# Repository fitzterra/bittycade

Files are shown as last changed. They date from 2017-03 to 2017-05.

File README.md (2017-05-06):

Bitty Arcade - Extremely Retro, Minimalist, Handheld Arcade Game.
=================================================================

This is my remix of an Arduino based handheld arcade game using an 8x8 LED
matrix as display.

The original inspiration and idea comes from [3CarrotsOnAStick] and is heavily
based on his [AbHhGd] - Arduino Based Hand-held Gaming Device instructable. Most
of the code and game ideas come from here, but I have had to make some heavy
code changes to compile in my environment as well as some changes that I wanted
to the code.

This device also uses the potentiometer as controler, while other devices like
this often uses 4 directional buttons. I decided to stick with the pot for now,
but this may change later.

For now the project is not completed yet, but I have a custom case designed and
it is printing now as I type, and I'm working on the code to allow rotation of
the display in 90° increments. I need this since for my case I had to rotate the
display by 90°, and I also want to clean up the display handling in the original
code which needs the sprites and coordinates to be mirrored.

I'll update here as the project progresses.

Updates
-------

* 2017-05-06: Added option for using a [rotary encoder](#rotEnc) for directional
    control.

Rotary Encoder for directional control
--------------------------------------
The initial implementation uses the optimised [Encoder] library by Paul
Stoffregen. The encoder used is a Chinese [knockoff] of the Keyes [KY-040]
rotary encoder.

In order to get this encoder to work, I had to solder a capacitor (100nF) across
each encoder output to ground. This was done right on the encoder on the board.
Without the caps, there would be too much switch bounce with totally erratic
output.

All games current has a delay during the play loop. Due to this delay the
encoder can not be polled for reliable positioning. To get around this for now,
the encoder should be connected to pins that allow external interrupts. For a
Nano or Uno, this will be pins 2 and 3, for example.
The [Encoder] library will automatically use interrupts in this case. It could
be an option to remove the delay in the main games play loop in future in order
to poll the encoder more frequently if using pins that do not support external
interrupts.

When using an encoder, the button on the encoder will also be made available via
the controller, but the individual game has to support this explicitly. An new
`Controller::anyButtonPressed` method has been added which will return true if
any button has been pressed, including an encoder button if available.

[3CarrotsOnAStick]: http://www.instructables.com/member/3CarrotsOnAStick/
[AbHhGd]: http://www.instructables.com/id/AbHhGD-the-Arduino-Based-Hand-held-Gaming-Device/
[Encoder]: http://www.pjrc.com/teensy/td_libs_Encoder.html
[knockoff]:https://www.banggood.com/KY-040-Rotary-Decoder-Encoder-Module-For-Arduino-AVR-PIC-p-914010.html 
[KY-040]: http://henrysbench.capnfatz.com/henrys-bench/arduino-sensors-and-input/keyes-ky-040-arduino-rotary-encoder-user-manual/

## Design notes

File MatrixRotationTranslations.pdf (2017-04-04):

8X8 LED Matrix Rotation Function Translations

C0 C1 C2 C3 C4 C5 C6 C7 | C0 C1 C2 C3 C4 C5 C6 C7
R0 | | | | R0
R1 | 0° | | | R1 | 90°
R2 | | | | R2
R3 | setPixel(r, c) | -> | setPixel(r, c) | R3 | setPixel(r, c) | -> | setPixel(c, rRev)
R4 | setRow(r, b) | -> | setRow(r, b) | R4 | setRow(r, b) | -> | setCol(rRev, b)
R5 | setCol(c, b) | -> | setCol(c, b) | R5 | setCol(c, b) | -> | setRow(c, inv(b))
R6 | | | | R6
R7 | | | | R7
C0 C1 C2 C3 C4 C5 C6 C7 | C0 C1 C2 C3 C4 C5 C6 C7
R0 | | | | R0
R1 | 270° | | | R1 | 180°
R2 | | | | R2
R3 | setPixel(r, c) | -> | setPixel(cRev, r) | R3 | setPixel(r, c) | -> | setPixel(rRev, cRev)
R4 | setRow(r, b) | -> | setCol(r, inv(b)) | R4 | setRow(r, b) | -> | setRow(rRev, inv(b))
R5 | setCol(c, b) | -> | setRow(cRev, b) | R5 | setCol(c, b) | -> | setCol(cRev, inv(b))
R6 | | | | R6
R7 | | | | R7

r: row number (0 – maxRows)
c: column number (0 – maxCols)
b: bit representation of row or column LEDs to switch on or off in a single byte, word, etc. depending on num LEDs in the row/col rRev: reversed row number = (maxRows – r)
cRev: reversed col number = (maxCols – c)
inv(b): function to invert a bit representation such that inv(b10011100) = b00111001

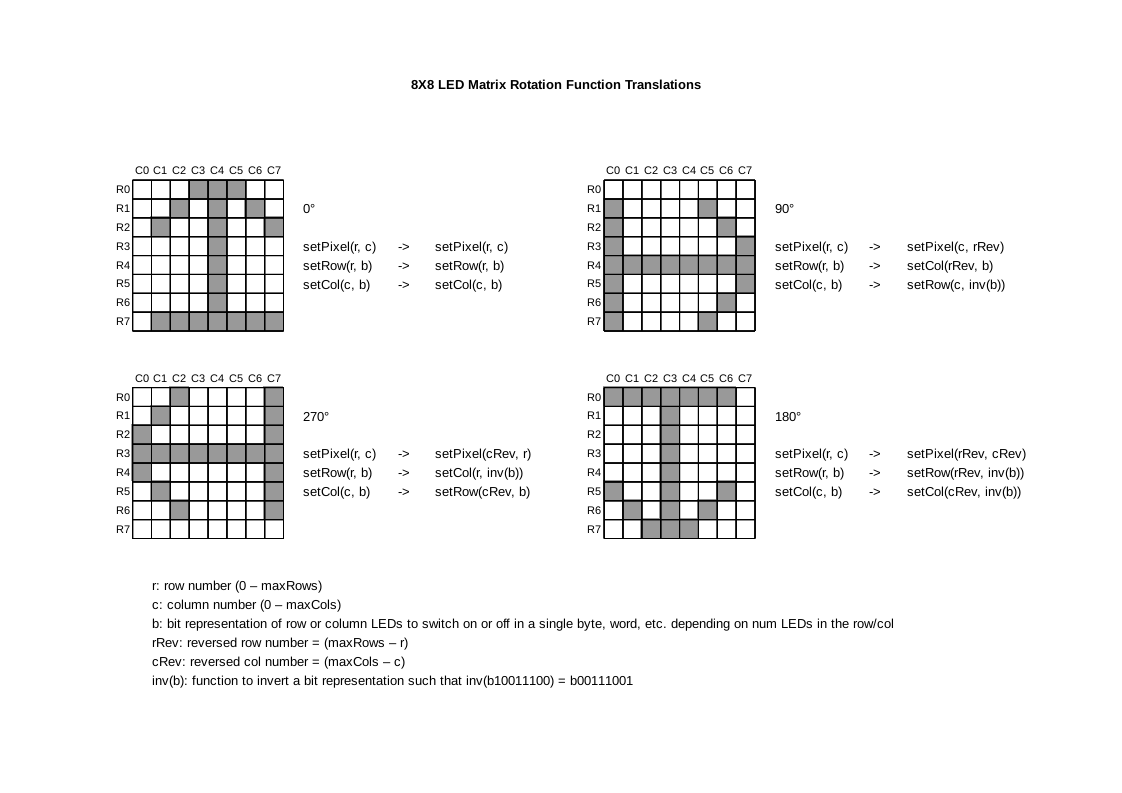
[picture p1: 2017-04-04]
MatrixRotationTranslations.png

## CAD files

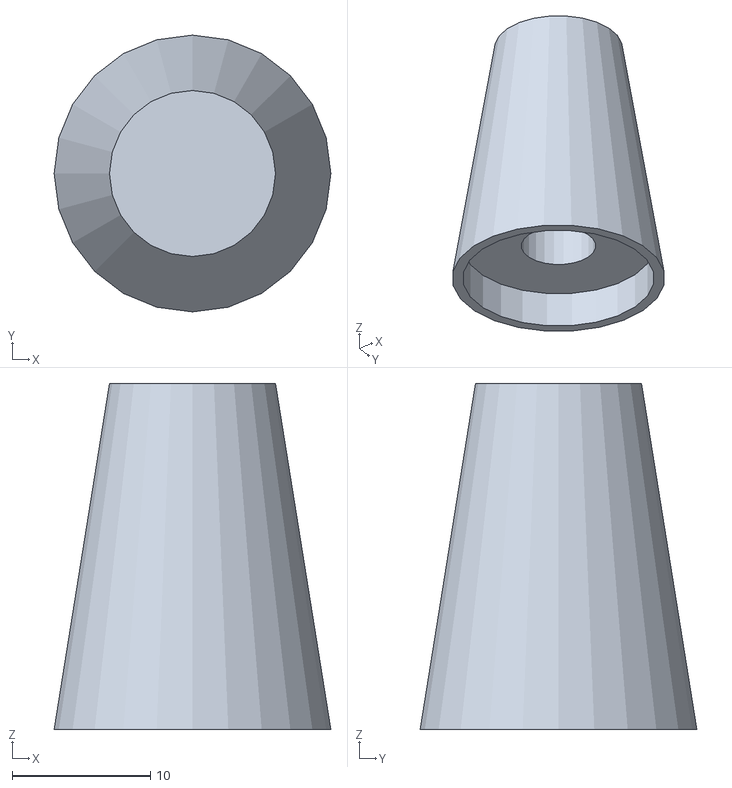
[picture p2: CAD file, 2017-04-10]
case/STLs/knob-v3.stl
20.0 x 20.0 x 25.0

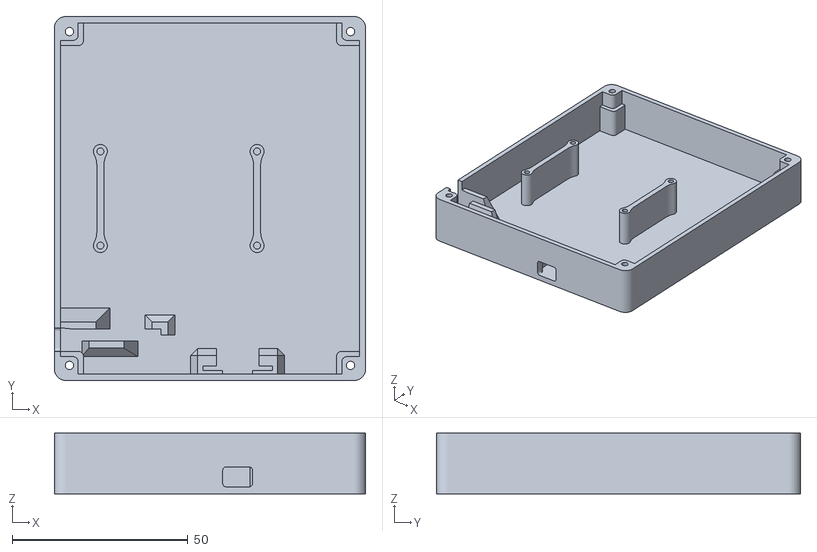
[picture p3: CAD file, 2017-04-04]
case/STLs/caseBottom-v3.stl
88.6 x 103.6 x 17.3

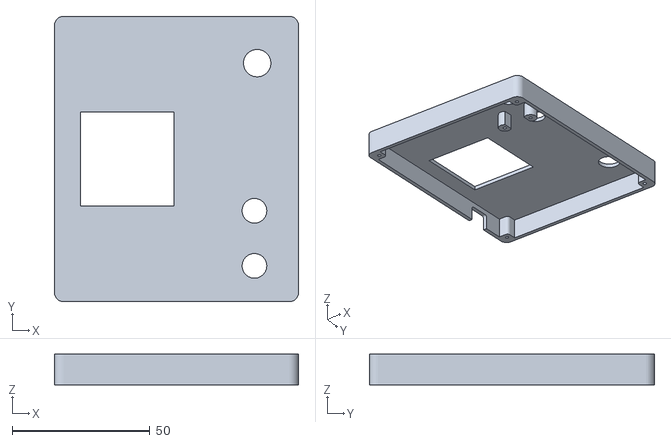
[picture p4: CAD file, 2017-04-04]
case/STLs/caseTop-v3.stl
88.6 x 103.6 x 11.2

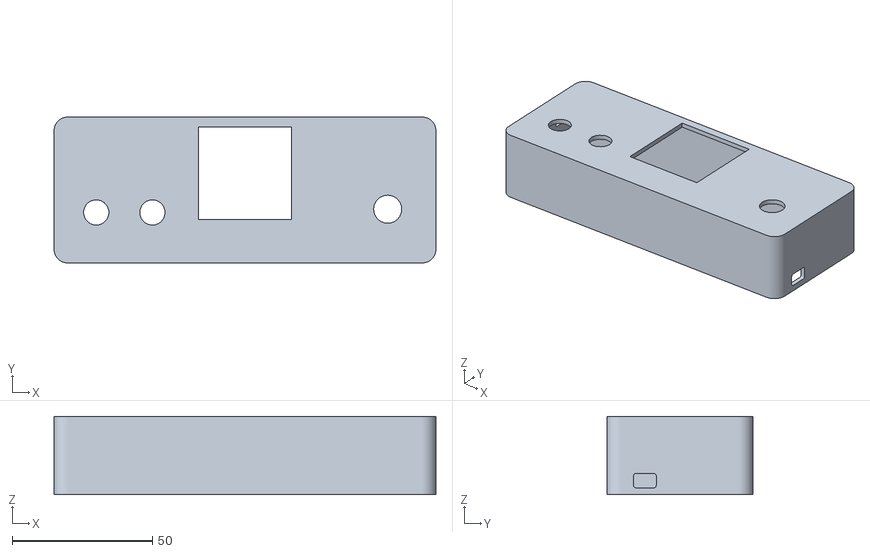
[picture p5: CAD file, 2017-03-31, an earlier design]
case/STLs/caseTop-v2.stl
136.0 x 52.0 x 27.8

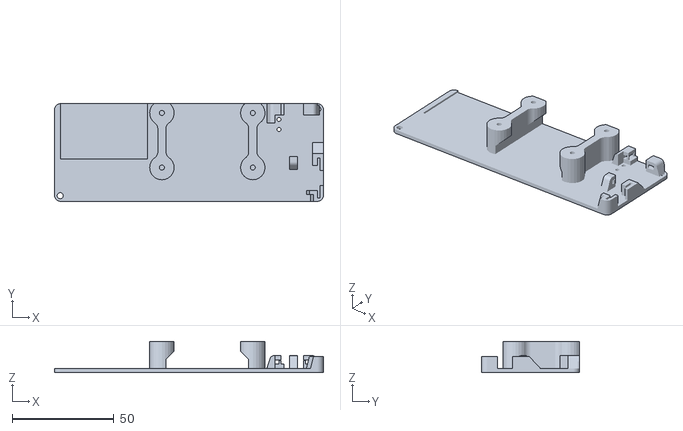
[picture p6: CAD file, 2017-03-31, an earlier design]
case/STLs/caseBottom-v2.stl
132.0 x 48.0 x 15.3

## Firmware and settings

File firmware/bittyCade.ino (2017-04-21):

#include "config.h"
#include "types.h"
#include "menu.h"
#include "pong.h"
#include "breakout.h"
#include "racing.h"
#include "snake.h"
#include "spaceInvaders.h"

Controller controller;
Display display;
Menu menu(&display, &controller);
Pong pong(&display, &controller);
BreakOut breakout(&display, &controller);
Racing racing(&display, &controller);
Snake snake(&display, &controller);
SpaceInvaders spaceinvaders(&display, &controller);

void setup() {
	Serial.begin(115200);
	randomSeed(analogRead(0));
}

void loop() {
    games game = menu.selectGame();
    Serial << "Game: " << game << endl;

    switch(game) {
        case gmPong:
            pong.play();
            break;
        case gmSpaceInvaders:
            spaceinvaders.play();
            break;
        case gmSnake:
            snake.play();
            break;
        case gmBreakOut:
            breakout.play();
            break;
        case gmRacing:
            racing.play();
            break;
    }
}

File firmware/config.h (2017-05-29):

#ifndef __CONFIG__H__
#define __CONFIG__H__

#include <stdint.h>
#include <Arduino.h>
// Make Serial streaming available to all
#include <Streaming.h>

// X Size of the LED matrix
#define LEDMATRIX_X 8
// Y Size of the LED matrix
#define LEDMATRIX_Y 8
// Set the rotation angle if needed - 0, 90, 180 or 270
#define DISPLAYROTATE 90

// Direction control. This can be a potentionmeter or a rotary encoder
#define CONTRL_POT 0
#define CONTRL_ROTARY 1
// Define which control to use here, and define the specific controller
// connections below
//#define DIRCONTR CONTRL_POT
#define DIRCONTR CONTRL_ROTARY


// Pin potentiometer is connected to
#if DIRCONTR==CONTRL_POT
    #define CONTROLLERPOTPIN A7
    // To invert the min/max directions of the poteniometer control, define
    // this:
    //#define INVERTPOTCONTROL
#else
    // Rotary encoder settings
    #define ROTARY_A 3
    #define ROTARY_B 2
    // Will use internal pullup for the button
    #define ROTARY_BUTTON 4
#endif

// Button pin - will use internal pullup
#define CONTROLLERRIGHTBUTTONPIN 5
//#define CONTROLLERRIGHTBUTTONPIN 2
// Button pin - will use internal pullup
#define CONTROLLERLEFTBUTTONPIN 6
//#define CONTROLLERLEFTBUTTONPIN 3
// Pin to which an LED can be connected which will be lit when the RIGHT button
// is pressed.
#define BUTTONLED 13
// Pins to talk to the LED display
//#define DIN 12
#define DIN 10
//#define CLK 11
#define CLK 12
//#define CS 10
#define CS 11
// This may be changed or defined elsewhere later!
#define NUM_GAMES 5 /// This excludes the Menu which is also handled as a game!
// Size of the menu sprite
#define MENUWIDTH NUM_GAMES*8
#define MENUHEIGHT 8

#endif // __CONFIG__H__

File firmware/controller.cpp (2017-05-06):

#include "controller.h"

/**
 * Controller constructor.
 * */
Controller::Controller() {
    objWidth = 0;

    pinMode(CONTROLLERRIGHTBUTTONPIN, INPUT_PULLUP);
    pinMode(CONTROLLERLEFTBUTTONPIN, INPUT_PULLUP);
    pinMode(BUTTONLED, OUTPUT);
#if DIRCONTR==CONTRL_ROTARY
    pinMode(ROTARY_BUTTON, INPUT_PULLUP);
#endif

    update();
}

void Controller::updateButtons() {
    // We are using the internal pullups for the buttons, so the state is invereted.
    rightButtonPressed = !digitalRead(CONTROLLERRIGHTBUTTONPIN);
    leftButtonPressed = !digitalRead(CONTROLLERLEFTBUTTONPIN);
    rotaryButtonPressed = !digitalRead(ROTARY_BUTTON);
}

void Controller::pause() {
    // We only enter this state when pausing is allowed and both buttons have
    // been pressed. Wait until both buttons have been released
    do {
        delay(100);
        updateButtons();
    } while(rightButtonPressed && leftButtonPressed);

    // Now we pause until any button is pressed to unpause
    do {
        delay(100);
        updateButtons();
    } while(!(rightButtonPressed || leftButtonPressed));

    // Unpaused, but wait for both buttons to be released again
    do {
        delay(100);
        updateButtons();
    } while(rightButtonPressed && leftButtonPressed);
}

#if DIRCONTR==CONTRL_POT
void Controller::updatePot() {
    // Get the pot analog position
    uint16_t potV = analogRead(CONTROLLERPOTPIN);
    // Set the real X position by mapping the pot value to the correct min and
    // max values after taking objWidth into account.
#ifdef INVERTPOTCONTROL
    xPos = map(potV, 0, 1023, xMax-objWidth, xMin);
#else
    xPos = map(potV, 0, 1023, xMin, xMax-objWidth);
#endif
}
#else
void Controller::updateEncoder() {
    xPos = encoder.read() / 4;

    if (xPos > xMax-objWidth) {
        xPos = xMax-objWidth;
        encoder.write(xPos * 4);
    } else if (xPos < xMin) {
        xPos = xMin;
        encoder.write(xPos * 4);
    }
}
#endif

void Controller::update() {
#if DIRCONTR==CONTRL_POT
    updatePot();
#else
    updateEncoder();
#endif
    
    // Get the button states.
    updateButtons();

    // Pausing?
    if (allowPause && rightButtonPressed && leftButtonPressed)
        pause();
  
    // Indicate the state of the right button
    digitalWrite(BUTTONLED, rightButtonPressed);
}

bool Controller::anyButtonPressed() {
    bool anyB = leftButtonPressed || rightButtonPressed;

#if DIRCONTR==CONTRL_ROTARY
    anyB = anyB || rotaryButtonPressed;
#endif

    return anyB;
}

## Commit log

2017-03-30 Initial commit for README and case design.
2017-03-31 Case modifications and STL generation
    Some modifications for the case bottom to move the Nano and charger
    board deeper into the base to allow the top to slide over without these
    components being in the way.
    Also added slots for the charger board and recessed the Nano carrier
    into the base by 1mm.
    [caseBottom.stl, caseTop.stl]
2017-04-04 New case design and renaming old designs.
    The v2 case did not work too well, specifically because of very limited
    space and the way the top and bottom parts fir together.
    The v3 case is slightly larger and has a split side wall between top and
    bottom. Hoping this would be a abetter desing.
2017-04-04 New case v3 STLs and rename old v2 STLs.
    [caseBottom-v2.stl, caseBottom-v3.stl, caseTop-v2.stl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]
2017-04-04 Add specifications needed for display rotation.
    [MatrixRotationTranslations.ods]
2017-04-06 Fix label for GND and VCC for LED display connector
2017-04-07 Fixed racing game direction control
    Due to not bit shifting the car position to the correct direction in the
    racing game, it was moving in the oposite direction to what was expected
    by the potentiometer control.
    Also add some (commented out for now) serial debug lines in various
    places, update code formatting, removed some older commented code and
    fixed the initial positioning of the paddle X position in Pong.
    [controller.cpp]
2017-04-10 Case updates and knob for potentionmeter
    Add holes in the case to clearly see the charge lights for the LiPo
    charger board.
    Cut the switch hole up a bit to allow the switch to be installed easier.
    The new cutout has a bridge to the other side to allow the upper bit to
    be added. This should be removed after printing using a knife.
    [knob-v3.stl]
2017-04-11 Improve breakout display update to not always redraw
    * The breakout display will now only redraw the paddle, ball and remove
    and hit bricks instead of redrawing the complete screen on every update
    loop.
    * Fix a bug in the clearBricks method where a for loop can not be used
    to cycle over a list with a continuesly changing length.
    * Add a new drawObject method to display to allow for an object to also
    be switched off.
2017-04-21 Add pause functionality to controller.
    The pause option will allow pausing the game at the controller level by
    pressing both buttons. Any button will then unpause. This is more for
    debugging and can be switched on/off at game setup time per game. To
    make this easier to use, the game base class will automatically switch
    pausing off after each have been played, effectively defaulting pausing
    ability to be off per game unless explicitly turned on.
    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
2017-04-21 Change menu entries from text to "images" :-)
    Menu options now better represent the game you are about to play, but
    the scrolling can cause a confusing visual. The plan to replace the
    potentiometer control with a rotary encoder should solve that by
    switching to the complete new menu option visual on each encoder
    movement.
    Also remove the pause option from SpaceInvaders.
2017-05-05 CHange to Arduino IDE version 1.8.2 from 1.6.11
2017-05-05 LibreOffice spreadsheet for easier bitmap menu generation
    [MenuGenerator.ods]
2017-05-06 Add initial support for a rotary encoder as control.
2017-05-29 Change menu animation from scrolling to clicking
    The scrolling game selection animation made it difficult to know where
    in the menu you are due to the menu screens not having well defined
    borders.
    This scrolling effect has been replaced with destinct sprites that are
    show with every click of the encoder wheel.
    This has not been tested with the potentionmeter controller yet!
    [config.h]
